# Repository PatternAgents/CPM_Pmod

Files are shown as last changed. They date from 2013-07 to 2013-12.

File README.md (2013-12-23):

CPM Pmod Adaptor
====================

PatternAgents CPM Pmod Adaptor

[PatternAgents CPM Pmod Adaptor  
*PatternAgents CPM Pmod Adaptor*](http://www.patternagents.com/projects/CPM_Pmod.html)

The "CPM Pmod Adaptor" board is designed to enable Cypress PSoC development boards to utilize Pmod peripherals.

The PatternAgents "CPM Pmod Adaptor" board supports :

Cypress CY8CKIT-001 : (Supports up to three (3) "CPM Pmod Adaptor")

Cypress CY8CKIT-030 : (Supports up to two (2) "CPM Pmod Adaptor")

Cypress CY8CKIT-050 : (Supports up to two (2) "CPM Pmod Adaptor")

Cypress CY3280-28xxx : (Supports one (1) "CPM Pmod Adaptor")

Cypress CY3280-22x45 : (Supports one (1) "CPM Pmod Adaptor")

(Not an Exhaustive list as more Cypress development boards are routinely released)

For information on the Digilent Pmod Specification, see http://www.digilentinc.com/Pmods/Digilent-Pmod_%20Interface_Specification.pdf

[  
*Licensing CC BY-NC-SA 4.0*](http://creativecommons.org/licenses/by-nc-sa/4.0/)

PatternAgents uses the increasingly popular business model called "Dual Licensing" 
in which both the open source software distribution mechanism and traditional commercial software distribution models are combined.

Open Source Projects:        

If you are developing and distributing open source applications under the Creative Commons CC BY-NC-SA 4.0, 
as published by the Creative Commons Foundation, then you are free to use the PatternAgents hardware/software under the CC BY-NC-SA 4.0 license. 
Please note that CC BY-NC-SA 4.0 requires that all modifications to the original code as well as all Derivative Works 
must also be released under the terms of the CC BY-NC-SA 4.0 license.

Closed Source Projects:

If you are developing and distributing traditional closed source or commercial applications, 
you must purchase a PatternAgents commercial use license, 
which is specifically designed for users interested in retaining the proprietary status of their designs and code. 
All PatternAgents commercial licenses expressly supersede the CC BY-NC-SA 4.0 license. 
This means that when you license the PatternAgents software under a commercial license, 
you specifically do not use the software under the CC BY-NC-SA 4.0 license and therefore you are not subject to any of its terms.
        
If you would like to use our designs for your own personal or educational use, have at it! 

Our public design repository is available at <a href="https://github.com/patternagents">Github</a>.

If you would like to produce our designs for commercial use, or as products for sale, 
please contact us to arrange for a Commercial Use license. We have many other designs, 
as well as options and extras that are not released publicly. 
We will also customize designs, firmware, and software for a reasonable fee, just contact us to discuss your requirements.

THIS SOFTWARE IS PROVIDED BY THE CONTRIBUTORS "AS IS" AND WITHOUT ANY EXPRESS OR IMPLIED WARRANTIES, 
INCLUDING, BUT NOT LIMITED TO, THE IMPLIED WARRANTIES OF MERCHANTABILITY AND FITNESS FOR A PARTICULAR PURPOSE ARE DISCLAIMED. 
IN NO EVENT SHALL THE COPYRIGHT OWNER OR CONTRIBUTORS BE LIABLE FOR ANY DIRECT, INDIRECT, INCIDENTAL, SPECIAL, EXEMPLARY, 
OR CONSEQUENTIAL DAMAGES (INCLUDING, BUT NOT LIMITED TO, PROCUREMENT OF SUBSTITUTE GOODS OR SERVICES; LOSS OF USE, DATA, 
OR PROFITS; OR BUSINESS INTERRUPTION) HOWEVER CAUSED AND ON ANY THEORY OF LIABILITY, WHETHER IN CONTRACT, 
STRICT LIABILITY, OR TORT (INCLUDING NEGLIGENCE OR OTHERWISE) ARISING IN ANY WAY OUT OF THE USE OF THIS SOFTWARE, 
EVEN IF ADVISED OF THE POSSIBILITY OF SUCH DAMAGE. 

-------------------------------------------------------------------------------------------

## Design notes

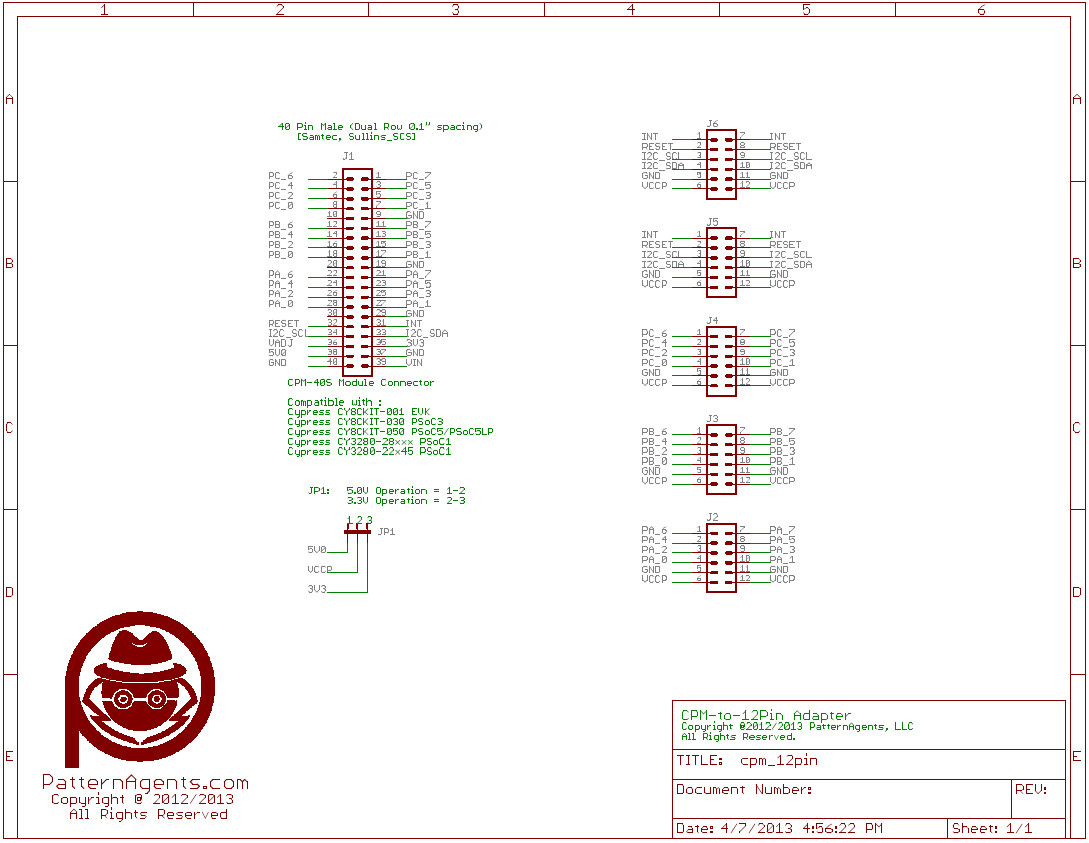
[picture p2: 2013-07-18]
CPM_Pmod/hardware/CPM_Pmod_SCH.jpg

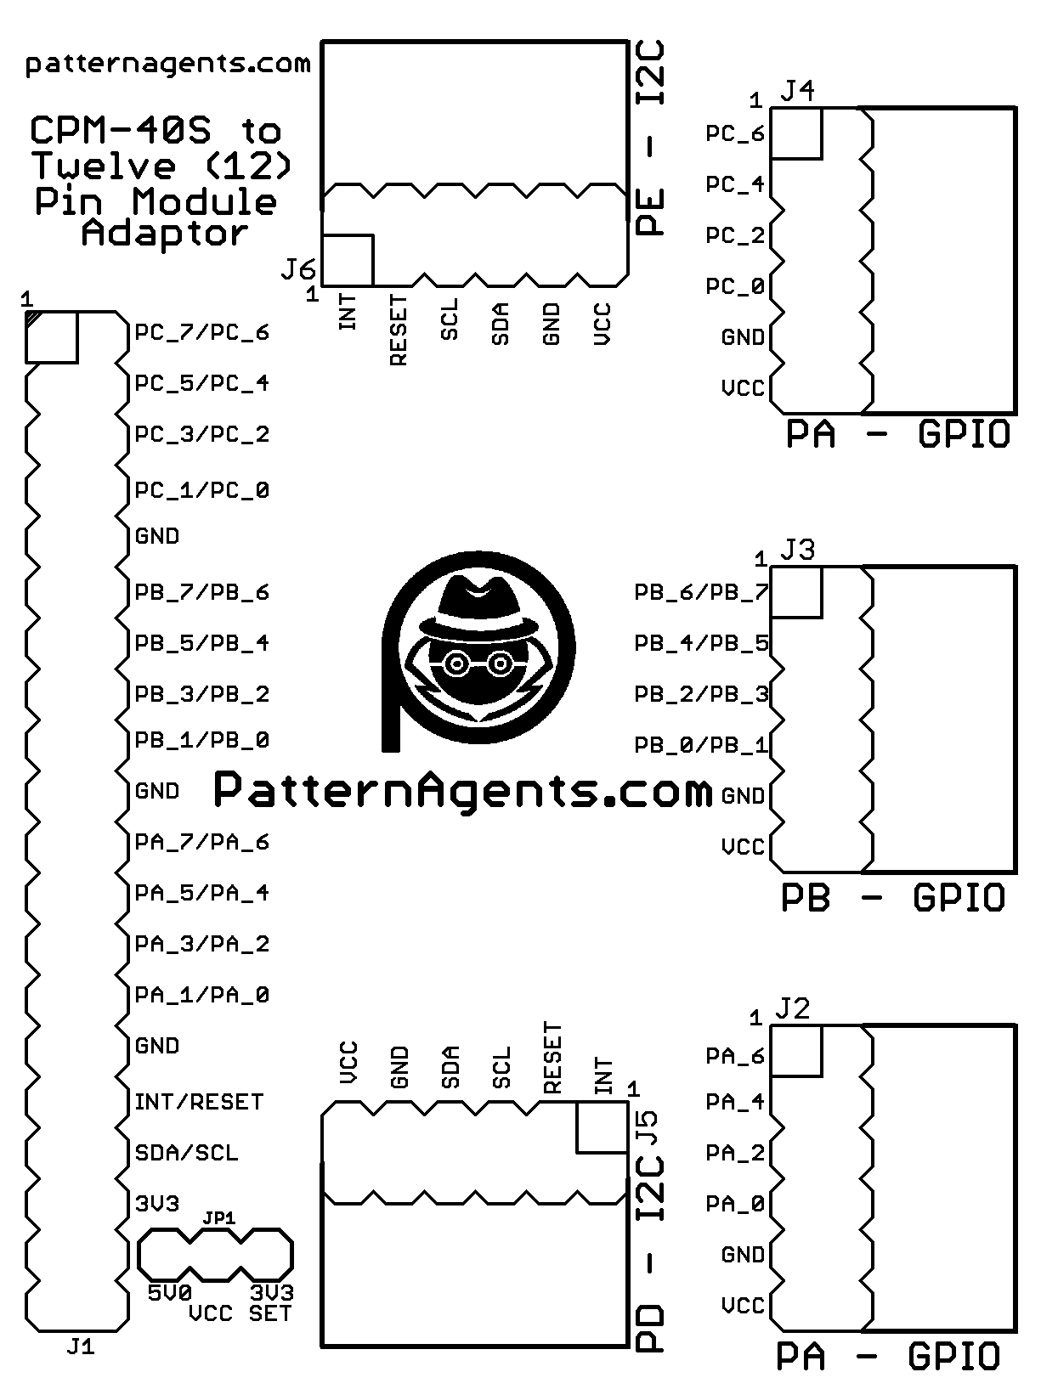
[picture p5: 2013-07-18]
CPM_Pmod/eagleUp/eagleUp_CPM_Pmod_top_silk.png

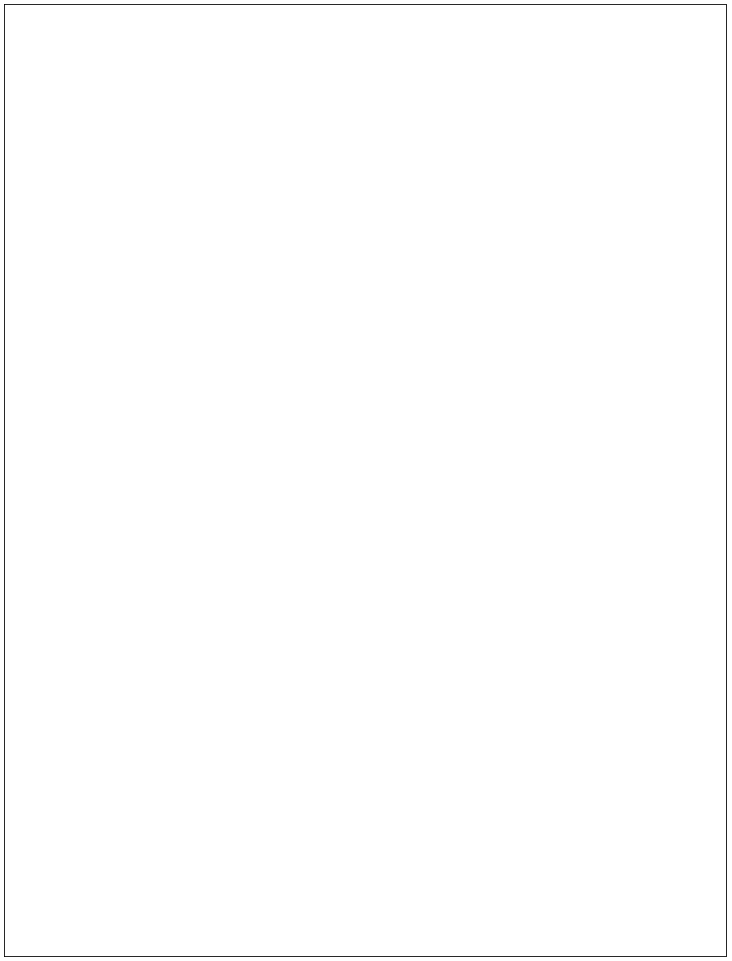
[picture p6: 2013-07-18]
CPM_Pmod/eagleUp/eagleUp_CPM_Pmod_outline.png

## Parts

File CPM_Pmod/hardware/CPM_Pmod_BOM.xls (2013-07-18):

CPM_to_12pin | Bill-of-Materials
CPM_to_12pin | Rev: 1.5 |  | REVISED | 2013-04-07
Description | Designator | Footprint | Quantity | Value | Substitution OK | Vender | VPN | Vendor2 | V2PN
CPM_to_12pin (Revison 1.5) | PCB |  | 1 |  |  |  | PCA#212A2102
Header, 40-Pin, Male, Right Angle | J1 | HDR40x2MRA | 1 | 40 | Yes | Samtec | TSW-120-08-T-D-RA | Digikey | 3M9485-ND
Header, 3-Pin, Male | JP1 | HDR3x1M | 1 | 3 | Yes | Samtec | TSW-103-05-T-S | Digikey | 609-3461-ND
Header,12_pin, Female, Right Angle | J2,J3,J4,J5,J6 | HDR6x2MRA | 5 | 12 | Yes | Samtec | SSW-106-02-F-D-RA | Digikey | S5520-ND
SPECIAL JUMPER INSTALLATION:
Jumper pins 1 and 2 "VOLT" on JP1 | SI-1 | JMP2x1 | 1 | 2-pos 0.1" | Yes | Digikey | A26228-ND | Digikey | 3M9580-ND
DO NOT POPULATE:
None.

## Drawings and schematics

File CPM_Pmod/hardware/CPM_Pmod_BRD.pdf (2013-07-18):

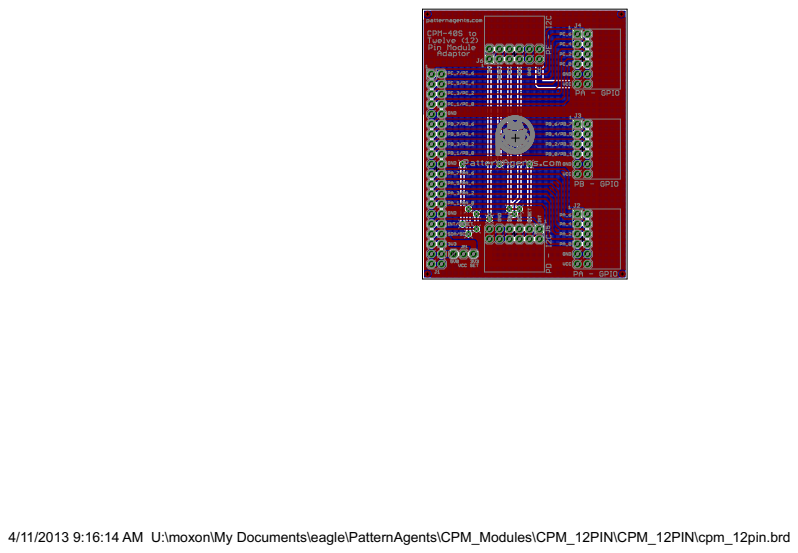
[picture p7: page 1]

4/11/2013 9:16:14 AM U:\moxon\My Documents\eagle\PatternAgents\CPM_Modules\CPM_12PIN\CPM_12PIN\cpm_12pin.brd

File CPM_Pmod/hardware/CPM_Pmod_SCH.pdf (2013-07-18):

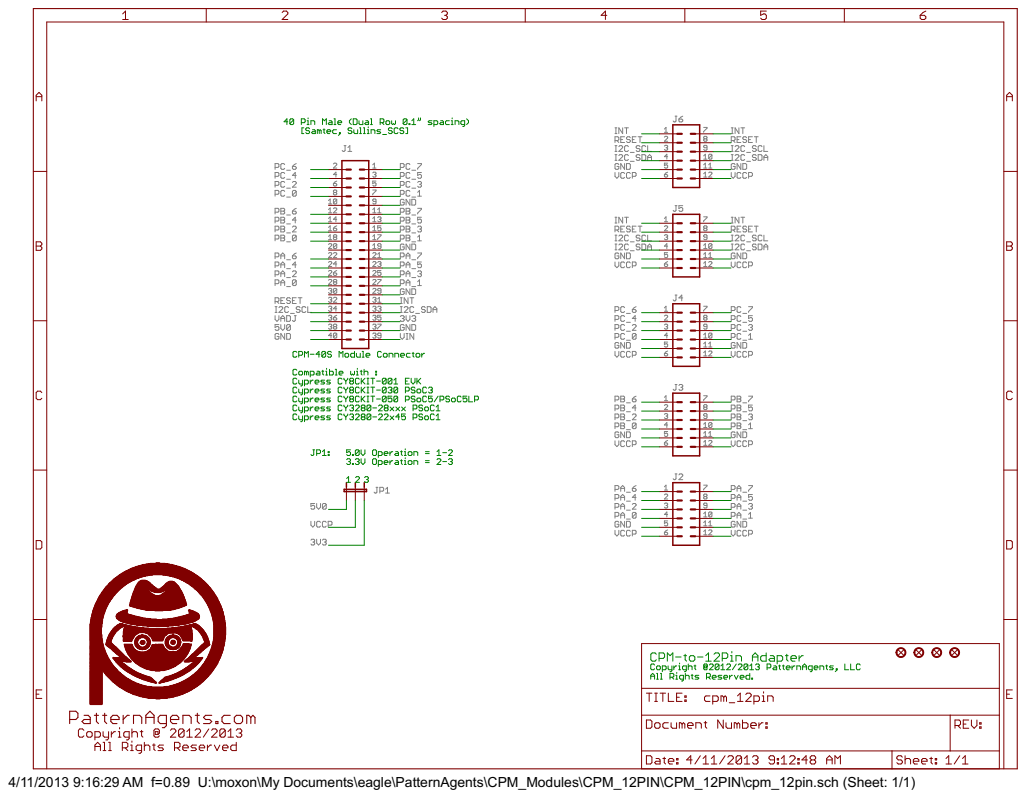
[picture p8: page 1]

4/11/2013 9:16:29 AM f=0.89 U:\moxon\My Documents\eagle\PatternAgents\CPM_Modules\CPM_12PIN\CPM_12PIN\cpm_12pin.sch (Sheet: 1/1)

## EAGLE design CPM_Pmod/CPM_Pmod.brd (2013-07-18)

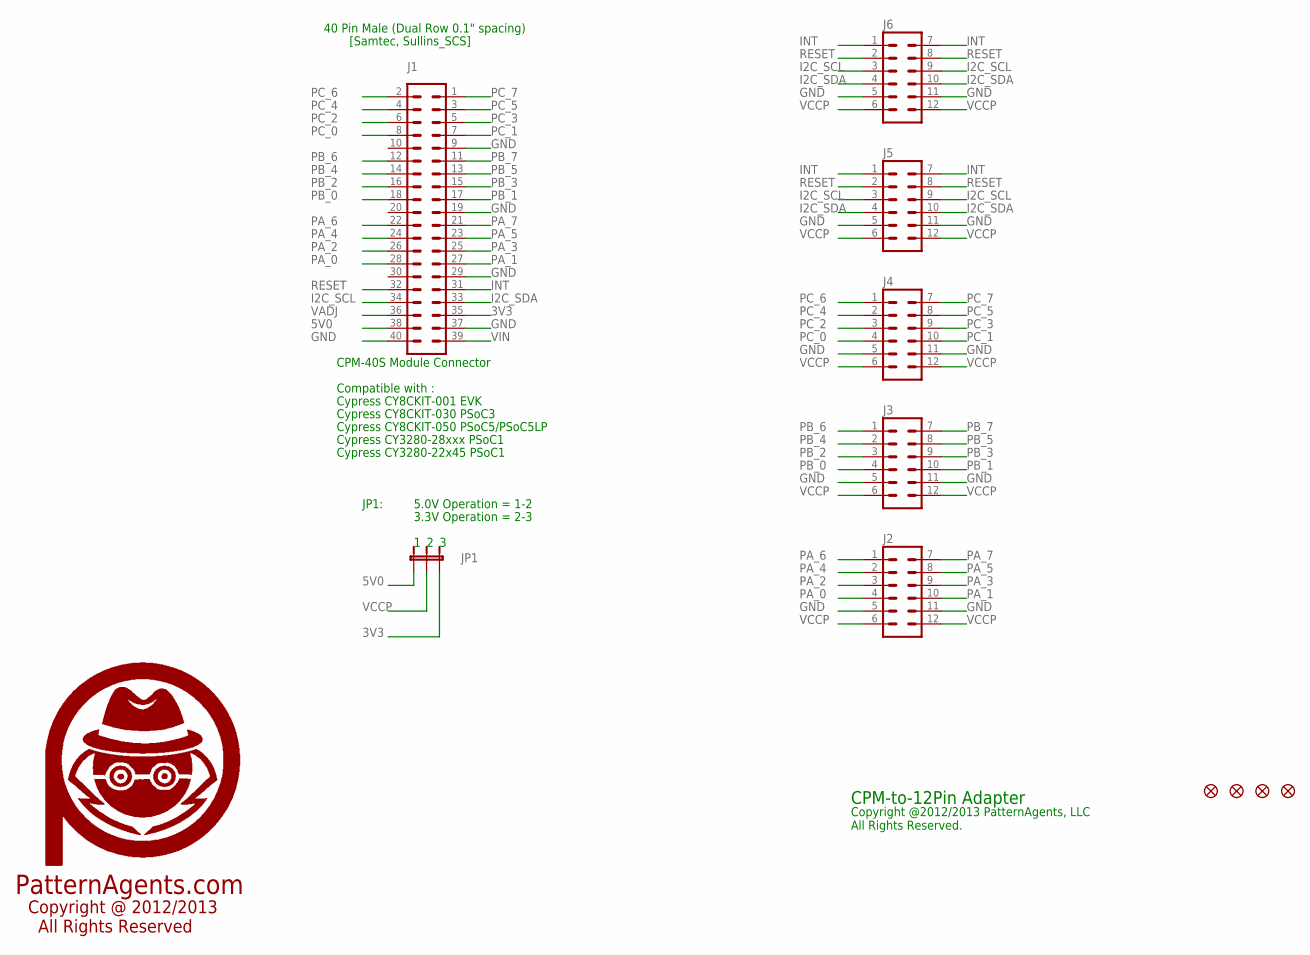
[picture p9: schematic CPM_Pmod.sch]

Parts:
J1: SULLINS_SCS; MA20-2
J2, J3, J4, J5, J6: MA06-2-PMOD
JP1: JUMPER-3PTH; 1X03
JP2, JP3, JP4, JP5: FIDUCIAL1.5X3; FIDUCIAL-1.5X3
U$1: LOGO_PA_AGENTLARGE; LOGO_PA_AGENT_LARGE

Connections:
3V3: J1.35, JP1.3
5V0: J1.38, JP1.1
GND: J1.9, J1.19, J1.29, J1.37, J1.40, J2.5, J2.11, J3.5, J3.11, J4.5, J4.11, J5.5, J5.11, J6.5, J6.11
I2C_SCL: J1.34, J5.3, J5.9, J6.3, J6.9
I2C_SDA: J1.33, J5.4, J5.10, J6.4, J6.10
INT: J1.31, J5.1, J5.7, J6.1, J6.7
PA_0: J1.28, J2.4
PA_1: J1.27, J2.10
PA_2: J1.26, J2.3
PA_3: J1.25, J2.9
PA_4: J1.24, J2.2
PA_5: J1.23, J2.8
PA_6: J1.22, J2.1
PA_7: J1.21, J2.7
PB_0: J1.18, J3.4
PB_1: J1.17, J3.10
PB_2: J1.16, J3.3
PB_3: J1.15, J3.9
PB_4: J1.14, J3.2
PB_5: J1.13, J3.8
PB_6: J1.12, J3.1
PB_7: J1.11, J3.7
PC_0: J1.8, J4.4
PC_1: J1.7, J4.10
PC_2: J1.6, J4.3
PC_3: J1.5, J4.9
PC_4: J1.4, J4.2
PC_5: J1.3, J4.8
PC_6: J1.2, J4.1
PC_7: J1.1, J4.7
RESET: J1.32, J5.2, J5.8, J6.2, J6.8
VADJ: J1.36
VCCP: J2.6, J2.12, J3.6, J3.12, J4.6, J4.12, J5.6, J5.12, J6.6, J6.12, JP1.2
VIN: J1.39

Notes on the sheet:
[Samtec, Sullins_SCS]
40 Pin Male (Dual Row 0.1" spacing)
CPM-40S Module Connector
Compatible with :
Cypress CY8CKIT-001 EVK
Cypress CY8CKIT-030 PSoC3
Cypress CY3280-28xxx PSoC1
Cypress CY3280-22x45 PSoC1
Cypress CY8CKIT-050 PSoC5/PSoC5LP
JP1:
5.0V Operation = 1-2
3.3V Operation = 2-3
CPM-to-12Pin Adapter
Copyright @2012/2013 PatternAgents, LLC All Rights Reserved.
PatternAgents.com
Copyright @ 2012/2013 All Rights Reserved

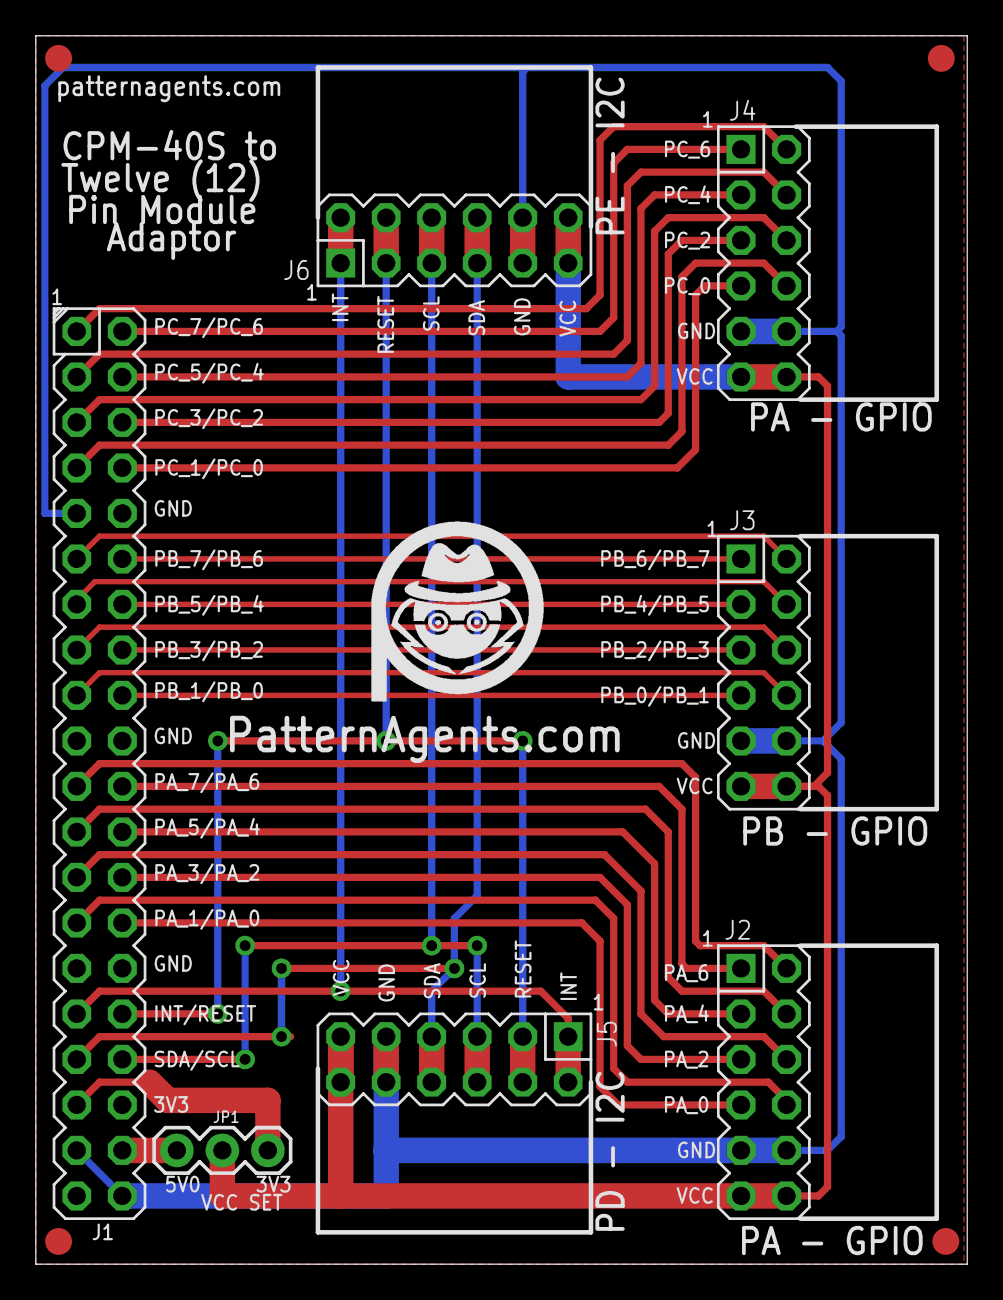
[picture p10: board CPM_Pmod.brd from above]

Board: 2 copper layers, 52.0 x 68.6 mm, 13 parts (1 on the bottom side), 32 nets.

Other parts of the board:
U$3: LOGO_PA_AGENTLARGE; LOGO_PA_AGENT_LARGE

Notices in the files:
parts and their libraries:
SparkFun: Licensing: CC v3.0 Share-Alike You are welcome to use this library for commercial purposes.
